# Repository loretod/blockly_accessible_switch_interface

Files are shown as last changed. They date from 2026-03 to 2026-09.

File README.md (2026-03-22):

# Blockly Keyboard Shortcuts Switch Interface
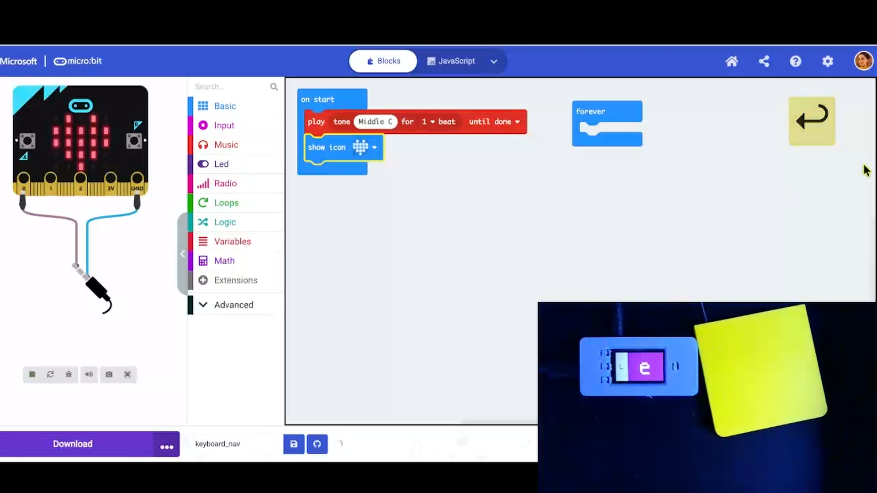
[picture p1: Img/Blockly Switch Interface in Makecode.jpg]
microbit makecode editor with image of a yellow 3d printed switch connected to the switch interface. The interface is showing the letter e on its screen.

## What It Is?
A DIY programmable switch interface that allows users with limited mobility to control computers using one or two adaptive switches. Built with an Adafruit Feather ESP32-S3 Rev TFT board, it features a built-in color display, two 3.5mm switch ports, and USB keyboard emulation of the Blockly keyboard shortcut commands. The device cycles through customizable keyboard commands, making computer access possible for users who cannot operate standard keyboards.

## Who It's For?
**Primary Users:** Individuals with motor impairments (cerebral palsy, muscular dystrophy, spinal cord injuries) who use adaptive switches for computer access and would like to complete in block based coding.

**Builders:** Occupational therapists, AT professionals, special education teachers, makers, family members, and caregivers creating affordable assistive technology solutions.

**Skill Level:** Intermediate - requires basic soldering, CircuitPython programming, and 3D printing.

## Key Features
✓ Two 3.5mm jack ports for standard AT switches  
✓ Built-in 240×135 color TFT display  
✓ USB HID keyboard (works with all computers, no drivers needed)  
✓ Fully customizable keycode list    
✓ 3D printable enclosure
✓ Open-source hardware and software  

## Bill of Materials
- Adafruit Feather ESP32-S3 Rev TFT (~$25)
- 2× 3.5mm mono jacks (~$2)
- Wire, screws, 3D printed enclosure
- **Total Cost: ~$30** (vs. $200-500 for commercial alternatives)

## Critical Safety Warnings

⚠️ **NOT A MEDICAL DEVICE** - This is an educational DIY project, not certified by FDA or any regulatory body. Not for life-critical applications.

⚡ **ELECTRICAL HAZARDS** - Ensure proper insulation and connections. Test thoroughly before use.

💻 **DEVICE BEHAVIOR** - Sends keystrokes to whatever application has focus. Test in safe environments first.

## Professional Guidance
- **Consult with occupational therapists or AT specialists** for assistance
- Professional assessment recommended for switch placement and configuration
- This device should complement, not replace, professional AT services

## License & Attribution

**Creative Commons Attribution-ShareAlike 4.0 International (CC BY-SA 4.0)**

You are free to:
- **Share** — copy and redistribute the material in any medium or format
- **Adapt** — remix, transform, and build upon the material for any purpose, even commercially

Under the following terms:
- **Attribution** — You must give appropriate credit to the original creator, provide a link to the license, and indicate if changes were made. You may do so in any reasonable manner, but not in any way that suggests the licensor endorses you or your use.
- **ShareAlike** — If you remix, transform, or build upon the material, you must distribute your contributions under the same CC BY-SA 4.0 license as the original.
- **No additional restrictions** — You may not apply legal terms or technological measures that legally restrict others from doing anything the license permits.

**Attribution Format:**
"Adaptive Switch Interface Device" by Zero Day Camp, licensed under CC BY-SA 4.0. Available at [[Blockly Accessible Interface](https://github.com/loretod/blockly_accessible_switch_interface/tree/main)].

When sharing modifications or derivatives:
- Maintain all safety warnings and disclaimers
- Clearly indicate what changes were made
- Share improvements back with the community
- Use the same CC BY-SA 4.0 license

This open-source approach ensures the assistive technology community can freely build, improve, and share solutions while protecting creators and maintaining safety standards.

## No Warranty Disclaimer
This project is provided **"as-is"** without warranties of any kind. The creator is not liable for any damages, injuries, or losses from use or misuse. You assume all responsibility for safe construction, testing, and operation. **Build and use at your own risk.**

## Getting Started
[Build instructions and video are available here](https://docs.google.com/presentation/d/e/2PACX-1vRLB-ssaZ2lQKfzIOw7MU3ilnS_D7XAcPhWdcv4CS0tsQ7e1NFE6QulaQyW4kVeWO49AM5KeUvafYBN/pub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)

---

## Next Iteration 
Roadmap for this project includes:
- Creating a wireless bluetooth version
- Creating a solderless version using the micro:bit controller
---

**Feedback?**
Please report any [issues and bugs](https://github.com/loretod/blockly_accessible_switch_interface/issues).

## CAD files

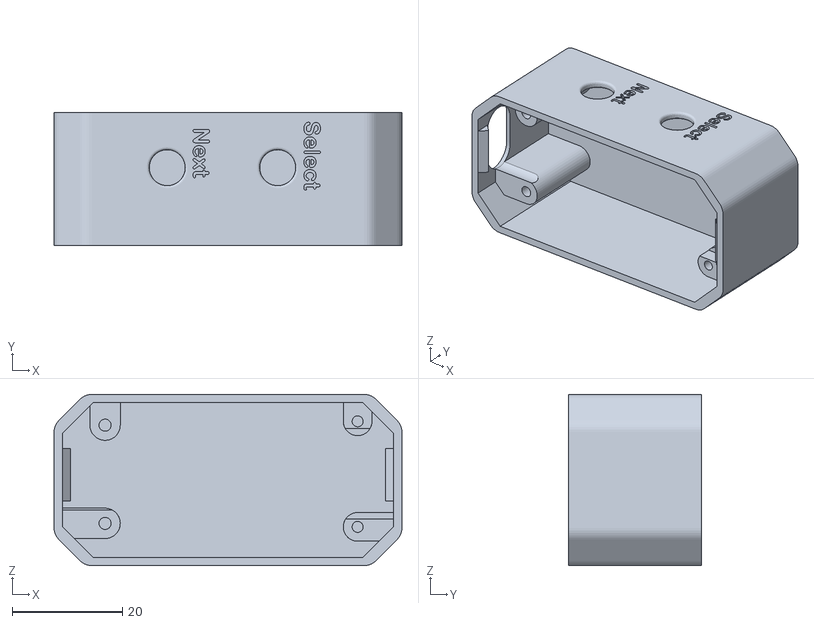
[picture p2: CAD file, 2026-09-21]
STL/TFT Switch Interface Case/Blockly Interface Bottom.stl
63.0 x 24.1 x 31.0

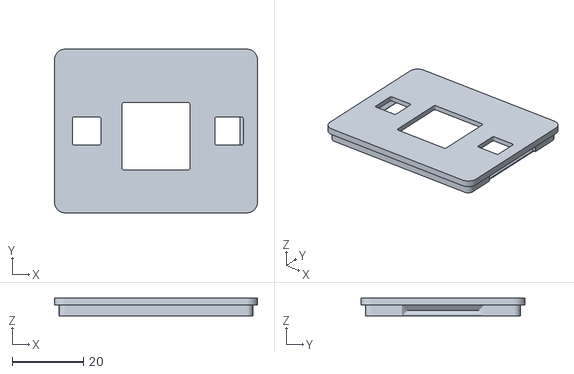
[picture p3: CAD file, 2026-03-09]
Working Files/Microbit Switch Case/Microbit Switch Case Top.stl
57.0 x 46.0 x 5.00

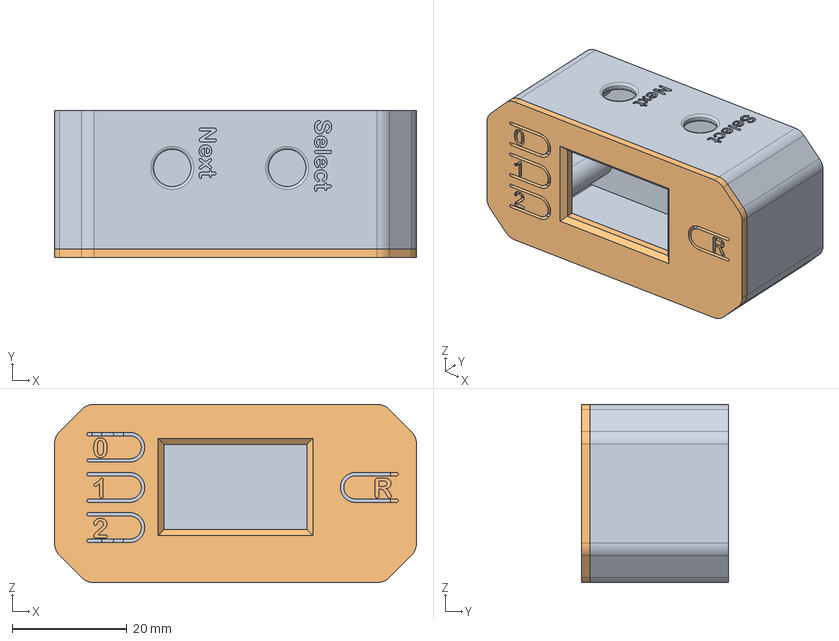
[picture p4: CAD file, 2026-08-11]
STL/TFT Switch Interface Case/Blockly Switch Interface.step
63.0 x 25.6 x 31.0 mm

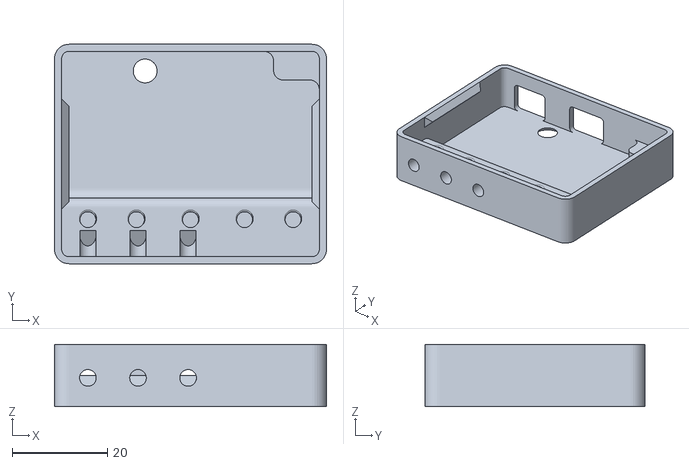
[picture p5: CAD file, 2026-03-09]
Working Files/Microbit Switch Case/Microbit Switch Case Bottom.stl
57.0 x 46.0 x 13.0

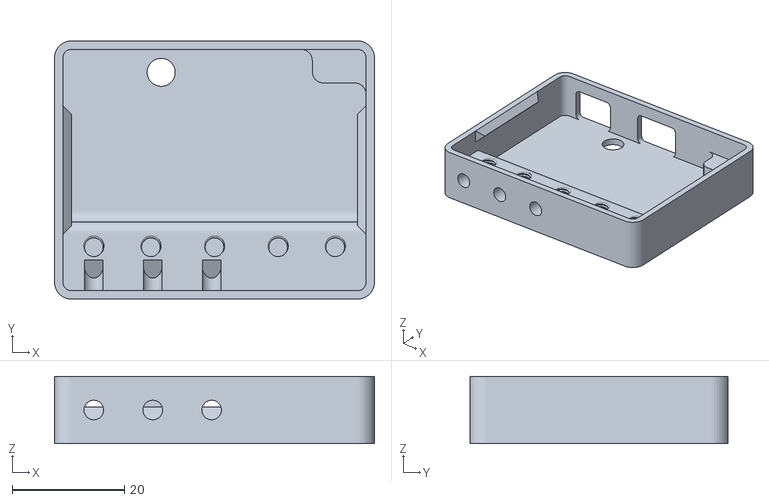
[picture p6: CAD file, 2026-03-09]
Working Files/Microbit Switch Case/Microbit Switch Bottom.stl
57.0 x 46.0 x 12.0

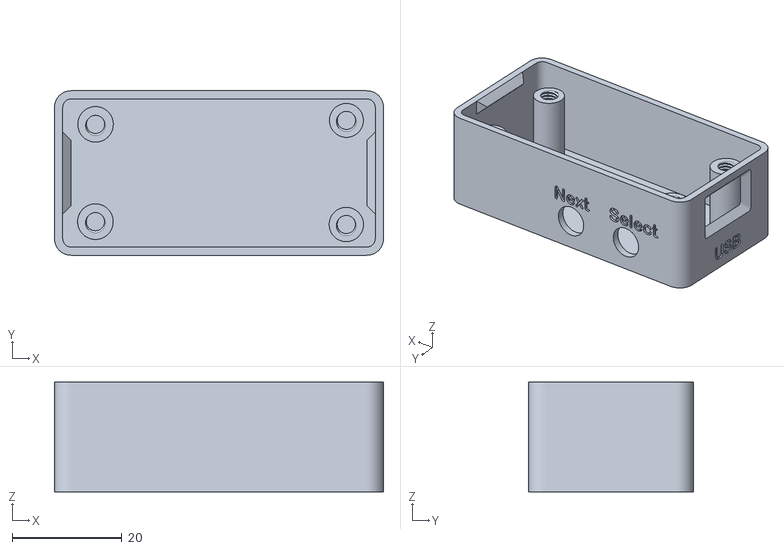
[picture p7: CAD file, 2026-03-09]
STL/TFT Switch Interface Case/TFT Case Bottom V3.stl
60.0 x 30.0 x 20.0

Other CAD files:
STL/TFT Switch Interface Case/TFT Case Bottom V2.stl
STL/TFT Switch Interface Case/Blockly Switch Interface.f3z

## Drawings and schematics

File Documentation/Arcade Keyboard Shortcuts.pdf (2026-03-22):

# Keyboard Shortcuts

### Makecode Arcade

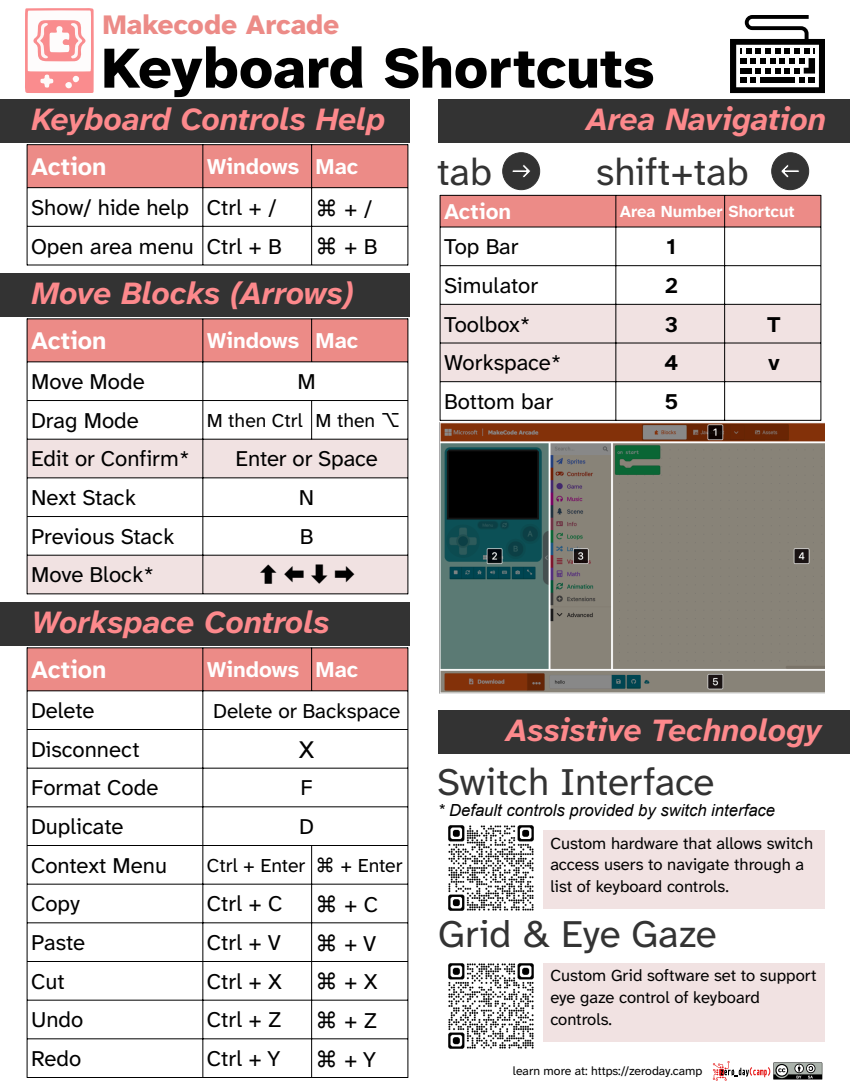
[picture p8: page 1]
Workspace Controls; Area Navigation; Assistive Technology; Open area menu; Ctrl + B; Top Bar; tab; Switch Interface; shift+tab

Keyboard Controls Help

Action | Windows | Mac
Show/ hide help | Ctrl + / | ⌘ + /

Action | Area Number | Shortcut

Move Blocks (Arrows)

Simulator | 2
Toolbox* | 3 | T
Workspace* | 4 | v
Bottom bar | 5

Move Mode | M
Drag Mode | M then Ctrl | M then ⌥
Edit or Confirm* | Enter or Space
Next Stack | N
Previous Stack | B
Move Block* | ⬆ ⬅ ⬇ ➡

Delete | Delete or Backspace
Disconnect | X
Format Code | F
Duplicate | D
Context Menu | Ctrl + Enter | ⌘ + Enter
Copy | Ctrl + C | ⌘ + C
Paste | Ctrl + V | ⌘ + V
Cut | Ctrl + X | ⌘ + X
Undo | Ctrl + Z | ⌘ + Z
Redo | Ctrl + Y | ⌘ + Y

* Default controls provided by switch interface

Custom hardware that allows switch
access users to navigate through a
list of keyboard controls.
Grid & Eye Gaze

Custom Grid software set to support
eye gaze control of keyboard
controls.

learn more at: https://zeroday.camp

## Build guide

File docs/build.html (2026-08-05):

Skip to main content

Step-by-step guide

# Build Instructions

Everything you need to assemble, wire, and install firmware — from parts list to first boot.

Watch the video walkthrough ↓ View Google Slide Instructions (https://docs.google.com/presentation/d/e/2PACX-1vRLB-ssaZ2lQKfzIOw7MU3ilnS_D7XAcPhWdcv4CS0tsQ7e1NFE6QulaQyW4kVeWO49AM5KeUvafYBN/pub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)

Step 01

## Build Instructions

Step 02

## Configuration (optional)

Without a config.py the device uses built-in defaults. To customise:

1. Open the Shortcut Configurator in your browser.
2. Select your OS and adjust shortcuts and timing as needed.
3. Click Generate config.py then Download config.py.
4. Copy the file to the root of CIRCUITPY — the device reloads automatically.

✓ Video walkthrough available (https://www.youtube.com/watch?v=kUqRWDpYum8)

Step 03

## First Boot

Power via USB. The TFT shows the mode-select screen with three zones:

- Left — D0 — Direct Switch Mode (Mode 0)
- Centre — D1 / A2 — Single-switch scanning mode
- Right — D2 / A1 — Two-switch direct mode

Press the relevant onboard button or external switch to enter a mode. To return to the mode-select screen, press the board's RESET button. In Mode 0 you can also hold an external switch for 1.5 s to exit (useful when the onboard buttons aren't reachable).

ℹ Can't reach the onboard D0 button? Double-click either external switch (A1 or A2) at the mode-select screen to jump straight into Mode 0 — Direct Switch.

Step 04

## Switch Modes Reference

### Single-Switch (A2)

One switch controls everything — short press to select, hold to auto-scan.

Short pressSelect & send current item

Hold (2s)Start auto-scanning

Press during scanSelect, stop scanning

D0Return to mode select

### Two-Switch (A1 + A2)

Separate navigate and select switches for faster, direct control.

A1 pressAdvance to next item

A2 pressSelect & send current item

D0Return to mode select

ℹ Single-switch and two-switch modes can also be selected at startup with the external switches: A2 (select) for single-switch mode, A1 (nav) for two-switch mode. To leave any mode, press the board's RESET button (Mode 0 can also be exited by holding a switch).

Mode 0

## Direct Switch Mode

Mode 0 maps each external switch directly to a single, immediate action — no scanning or navigation required. It is designed for users who need a simple, low-effort input method or who want to control mouse and media functions with their switches.

### Direct Switch (Mode 0)

Each switch fires one action immediately on press. Default: Switch 1 = Enter, Switch 2 = Tab. Fully configurable in the Shortcut Configurator.

A1 tapSwitch 1 action (default: Enter)

A2 tapSwitch 2 action (default: Tab)

A1/A2 hold (1.5 s)Return to mode select

RESET buttonReturn to mode select

### How to enter Mode 0

Method | How | Best for
D0 | Press onboard D0 button at mode-select screen | Initial setup, tester access
Double-click | Double-click either external switch (A1 or A2) at the mode-select screen within 0.4 s | Users who cannot reach onboard buttons
config.py | Run run_direct_switch_mode() as the first call in the main loop | Dedicated single-purpose device

ℹ Because a single external-switch click waits briefly (the double-click window, default 0.4 s) to watch for a second click, entering single- or two-switch mode via an external switch has a short deliberate delay. The onboard D1 / D2 buttons enter those modes instantly.

### How to exit Mode 0

Method | How | Best for
Hold a switch | Hold A1 or A2 for 1.5 s — a short tap still fires the action, only a long hold exits | Users who entered by double-click
RESET | Press the board's onboard RESET button | When the board is reachable

### Supported action types

Type | What it does | Example
Keyboard key | Press (and release) any key or key combo | Enter, Tab, Ctrl+C, Cmd+Space
Mouse click | Left, right, or middle button click | Left click for activation
Mouse scroll | Scroll up or down by N ticks per press | Scroll down a page
Mouse move | Move pointer by X/Y pixels per press | Nudge cursor right
Media control | Play/pause, volume, track skip, mute, brightness | Play/pause music

ℹ Customise both switch actions in the Shortcut Configurator under Mode 0 — Direct Switch Actions, then download and drop the generated config.py onto your device.

Step 05

## Display (optional)

The Feather ESP32-S3 TFT has a small built-in display that shows the active shortcut, next shortcut and connection status. Users with low vision may benefit from the Display Tool as an alternative to the small onboard screen. The web app tool provides a larger, high contrast, more readable interface for displaying information and text to speech support if enabled.

Watch the walkthrough below for a live demo of the display in action.

✓ Note: This tool is only support by Chrome or Edge browsers that support WebUSB. TTS is only supported on computers. This tool has not yet been tested on mobile devices.

BASI.

Open source — Creative Commons CC BY-SA 4.0

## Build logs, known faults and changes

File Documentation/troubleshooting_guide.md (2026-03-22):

# Switch Interface Troubleshooting Guide

## Quick Diagnostic Checklist
Before diving into specific issues, verify these basics:
- [ ] CircuitPython 9.0+ or 10.x is installed
- [ ] TinyUF2 Bootloader was updated
- [ ] All required libraries are in the `lib` folder
- [ ] USB cable is a data cable (not charge-only)
- [ ] Switches are normally-open momentary type
- [ ] Board backlight is on (screen should glow)
- [ ] Serial console shows no error messages

---

## Display Issues

### Problem: Display is completely blank/black
**Symptoms:** Screen is dark, no text visible, but device appears powered

**Solutions:**
1. **Check backlight pin**
   - Open serial console and look for "Backlight enabled" message
   - If missing, backlight pin detection failed
   - Manually set backlight: `backlight = digitalio.DigitalInOut(board.D45)`

2. **Verify display initialization**
   - Serial console should show "Display initialized: 240x135"
   - If you see "AttributeError: 'NoneType'", display failed to initialize
   - Check that `adafruit_st7789.mpy` is in the `lib` folder

3. **Test with simple code**
   ```python
   import board
   import displayio
   import terminalio
   from adafruit_display_text import label
   
   displayio.release_displays()
   spi = board.SPI()
   display_bus = displayio.FourWire(spi, command=board.D6, 
                                     chip_select=board.D5, reset=board.D9)
   import adafruit_st7789
   display = adafruit_st7789.ST7789(display_bus, width=240, height=135,
                                     rotation=270, rowstart=40, colstart=53)
   
   splash = displayio.Group()
   text = label.Label(terminalio.FONT, text="TEST", color=0xFFFFFF, x=50, y=50, scale=3)
   splash.append(text)
   display.root_group = splash
   ```

4. **Library version mismatch**
   - CircuitPython 10.x requires 10.x libraries
   - Download matching library bundle from circuitpython.org/libraries
   - Delete old libraries and install fresh ones

### Problem: Display shows garbage/corrupted text
**Symptoms:** Screen shows random pixels, wrong colors, or garbled text

**Solutions:**
1. **Check SPI configuration**
   - Baudrate too high: Lower from 24MHz to 12MHz
   - Change: `spi.configure(baudrate=12000000)`

2. **Verify rotation and offsets**
   - Wrong rotation causes display issues
   - Ensure: `rotation=270, rowstart=40, colstart=53`
   - Try rotation values: 0, 90, 180, 270

3. **Power supply issue**
   - USB port may not provide enough power
   - Try different USB port or powered hub

### Problem: Display works but text is too dim
**Symptoms:** Can barely see text, very faint display

**Solutions:**
1. **Backlight not fully on**
   - Verify backlight pin: `backlight.value = True`
   - Try toggling: `backlight.value = False` then `backlight.value = True`

2. **Check power**
   - Low USB power can dim display
   - Test with different USB cable

---

## Switch Input Issues

### Problem: Switches don't respond at all
**Symptoms:** Pressing switches does nothing, no navigation or selection

**Solutions:**
1. **Test switch continuity**
   - Use multimeter to verify switch closes circuit when pressed
   - Check 3.5mm jack wiring: Tip and Sleeve should connect when pressed
   - Verify jack is fully inserted

2. **Check pin connections**
   - Navigate switch: Jack tip → A0, sleeve → GND
   - Select switch: Jack tip → A1, sleeve → GND
   - Verify solder joints are solid

3. **Test pins in serial console**
   - Add debug code:
   ```python
   print(f"A0 value: {switch_nav.value}")
   print(f"A1 value: {switch_select.value}")
   ```
   - Should show `True` when not pressed, `False` when pressed

4. **Wrong switch type**
   - Device requires **normally-open** switches
   - Normally-closed switches will behave reversed
   - Latching switches won't work (must be momentary)

### Problem: Switches trigger erratically or double-trigger
**Symptoms:** Single press causes multiple actions, unpredictable behavior

**Solutions:**
1. **Increase debounce time**
   - Default is 0.2 seconds
   - Increase: `debounce_time = 0.3` or `0.4`
   - Helps with bouncy mechanical switches

2. **Check for loose connections**
   - Wiggle jack while testing
   - Resolder connections if intermittent
   - Verify jack is firmly mounted

3. **Electrical noise**
   - Add small capacitor (0.1µF) across switch terminals
   - Keep switch wires short and away from power wires
   - Use shielded cable if available

### Problem: Only one switch works
**Symptoms:** One switch navigates/selects correctly, other does nothing

**Solutions:**
1. **Verify both pins configured**
   - Check both `switch_nav` and `switch_select` are defined
   - Ensure both have `pull = digitalio.Pull.UP`

2. **Test individual pins**
   - Swap switch connections to isolate problem
   - If problem follows the switch → bad switch/cable
   - If problem stays with pin → check code/wiring

3. **Pin conflict**
   - Ensure A1 and A2 aren't used elsewhere
   - Check for pin conflicts with display or other features

---

## USB HID / Keyboard Issues

### Problem: Keystrokes not received by computer
**Symptoms:** Display shows "SENT!" but computer doesn't respond

**Solutions:**
1. **Check USB HID initialization**
   - Serial console should show "USB HID Keyboard initialized"
   - If missing, HID failed to initialize
   - Try unplugging and replugging USB

2. **Verify computer recognizes device**
   - **Windows:** Device Manager → Human Interface Devices → "Adafruit Feather ESP32-S3"
   - **Mac:** System Information → USB → Look for keyboard device
   - **Linux:** `lsusb` should show Adafruit device

3. **Test with text editor**
   - Open Notepad/TextEdit
   - Click inside to give it focus
   - If works in editor but not other apps → app-specific issue

4. **Security software blocking**
   - Antivirus may block USB HID devices
   - Temporarily disable to test
   - Add exception for CircuitPython device

### Problem: Wrong keys being sent
**Symptoms:** Press switch, but wrong character appears

**Solutions:**
1. **Verify keycode mapping**
   - Check KEYCODES array matches display
   - Ensure index is correct
   - Common mistake: Display shows one key but sends another

2. **Keyboard layout mismatch**
   - Some keys depend on OS keyboard layout
   - Test with basic keys first (letters, numbers, arrows)
   - Avoid symbols if layout uncertain

3. **Stuck modifier keys**
   - If SHIFT/CTRL/ALT stuck, all keys will be wrong
   - Add to code: `keyboard.release_all()` before every send

---

## CircuitPython Issues

### Problem: Code doesn't auto-reload
**Symptoms:** Changes to code.py don't take effect

**Solutions:**
1. **Manual reload**
   - Press CTRL+D in serial console
   - Or press physical RESET button
   - Or save code.py again

2. **Auto-reload disabled**
   - Check for `supervisor.disable_autoreload()`
   - Remove or comment out

3. **USB connection issue**
   - Unplug and replug USB
   - Try different USB cable/port
   - Check CIRCUITPY drive is mounted

### Problem: "ImportError" for libraries
**Symptoms:** Error says module not found

**Solutions:**
1. **Library not installed**
   - Download CircuitPython library bundle
   - Match version to your CircuitPython version
   - Copy required libraries to `lib` folder

2. **Wrong library version**
   - CircuitPython 10.x needs 10.x libraries
   - Check bundle version number
   - Delete old libraries and reinstall

3. **Library name mismatch**
   - Ensure exact spelling: `adafruit_display_text` (folder)
   - Not `.mpy` files for folders
   - Check capitalization

### Problem: "MemoryError" when running code
**Symptoms:** Code runs then crashes with memory error

**Solutions:**
1. **Too many libraries**
   - Remove unused imports
   - Use `.mpy` compiled libraries instead of `.py`
   - Delete unused libraries from `lib`

2. **Display groups too large**
   - Reduce number of label objects
   - Simplify graphics
   - Reuse groups instead of creating new ones

3. **Firmware issue**
   - Update to latest CircuitPython
   - Try stable vs. beta versions

---

## Common Error Messages

| Error | Meaning | Solution |
|---|---|---|
| `AttributeError: 'module' object has no attribute 'TFT_CS'` | Pin names changed in CP version | Use pin detection code or manual pin assignment |
| `AttributeError: 'NoneType' object has no attribute 'width'` | Display failed to initialize | Check display libraries and initialization code |
| `ImportError: no module named 'adafruit_st7789'` | Missing display driver | Install `adafruit_st7789.mpy` in lib folder |
| `OSError: [Errno 19] No such device` | USB HID not available | Check `usb_hid` is enabled in boot.py |
| `ValueError: Not a valid keycode` | Wrong keycode constant | Use `Keycode.NAME` format, check spelling |
| `MemoryError` | Out of RAM | Remove unused code/libraries, use .mpy files |

---

## Still Having Issues?

### Diagnostic Code
Run this to check your setup:
```python
import board
import supervisor
print(f"CircuitPython version: {supervisor.runtime.version}")
print(f"Board: {board.board_id}")
print("Available pins:", dir(board))
```

### Where to Get Help
1. [**Adafruit Forums**](forums.adafruit.com)
2. [**CircuitPython Discord**](adafru.it/discord)
3. **GitHub Issues:** [Project repository Issues](https://github.com/loretod/blockly_accessible_switch_interface/issues)

### Before Asking for Help
Include this information:
- CircuitPython version
- Board type (Feather ESP32-S3 Rev TFT)
- Libraries installed (and versions)
- Complete error message from serial console
- What you've already tried
- Photo of wiring if relevant

---

## Safety Reminder
If experiencing any of these issues, **stop use immediately**:
- 🔥 Burning smell or smoke
- ⚡ Sparks or short circuits
- 💧 Water damage or moisture inside

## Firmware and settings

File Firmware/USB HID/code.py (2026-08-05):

"""
Switch Interface for Adafruit Feather ESP32-S3 Rev TFT
USB HID Version — Triple Mode with Onboard Mode Selection
Uses built-in 1.14" 240x135 color TFT display
Compatible with CircuitPython

EXTERNAL SWITCHES (3.5mm jacks, wired to GND, Pull.UP active LOW):
  A1 → Navigate switch
  A2 → Select / Single switch

ONBOARD BUTTONS / EXTERNAL SWITCHES (mode selection):
  D0 (onboard)             → Direct Switch Mode (Mode 0)
  D1 (onboard) or A2       → Enter Single-Switch Scanning Mode
  D2 (onboard) or A1       → Enter Two-Switch Mode

  EXTERNAL SWITCHES at the mode-select screen:
    Single-click A2 (select) → Single-Switch Scanning Mode
    Single-click A1 (nav)    → Two-Switch Mode
    Double-click A1 or A2    → Direct Switch Mode (Mode 0)
  (Note: a single external-switch click waits one DOUBLE_CLICK_WINDOW before
   committing, so a second click can be detected for Mode 0.)

─── DIRECT SWITCH MODE (Mode 0) ───────────────────────
  A1 TAP    : Send Switch 1 action (default: Enter)
  A2 TAP    : Send Switch 2 action (default: Tab)
  A1/A2 HOLD (≥ SWITCH_HOLD_EXIT_SECS) : Back to Mode Select
  D0        : Back to Mode Select
  (Customisable via config.py — supports keyboard, mouse & media)

─── SINGLE-SWITCH MODE ─────────────────────────────────────
  A2 SHORT PRESS  (≤ MAX_SHORT_PRESS_SECS)  : Select & send current item
  A2 HOLD         (≥ HOLD_TO_SCAN_SECS)     : Start auto-scanning
  A2 PRESS during scan                      : Select & send, stop scanning
  D0                                        : Back to Mode Select

─── TWO-SWITCH MODE ────────────────────────────────────────
  A1  : Advance to next item
  A2  : Select & send current item
  D0  : Back to Mode Select

(D0 is dual-purpose: at the mode-select screen it jumps straight into
 Mode 0; from inside ANY active mode it returns to the mode-select screen.)

─── SUBMENUS (Modes 1 & 2 only) ─────────────────────────────
  Any KEYCODES entry can be a SUBMENU ENTRY POINT (it has a
  "submenu" list). Selecting it sends its own keycode first
  (e.g. to open an on-screen menu on the host) — unless "kc"
  is empty, which marks a pure organisational folder with no
  keystroke of its own — then the scan/nav list switches to
  just that entry's child items. If the entry's "auto_exit"
  is True, picking a child item automatically returns to the
  parent list afterwards. If False, a synthetic "◂ back" item
  is added to the child list so several child items can be
  picked in a row before manually returning.
"""

import time
import board
import digitalio
import displayio
import terminalio
try:
    from fourwire import FourWire
except ImportError:
    from displayio import FourWire
import adafruit_st7789
from adafruit_display_text import label
import usb_hid
from adafruit_hid.keyboard import Keyboard
from adafruit_hid.keycode import Keycode

# Optional mouse / consumer control — only used by Mode 0 (Direct Switch).
# Imported here (not lazily) so config.py can reference Mouse /
# ConsumerControlCode directly when defining SWITCH1_ACTION / SWITCH2_ACTION.
try:
    from adafruit_hid.mouse import Mouse
    _mouse_available = True
except ImportError:
    _mouse_available = False

try:
    from adafruit_hid.consumer_control import ConsumerControl
    from adafruit_hid.consumer_control_code import ConsumerControlCode
    _consumer_available = True
except ImportError:
    _consumer_available = False

print("Starting Switch Interface...")

# ===============================================
# ===== USER CONFIGURABLE VARIABLES =====
# ===============================================

# --- Single-Switch Mode ---
# How long (seconds) A2 must be held to begin auto-scanning
HOLD_TO_SCAN_SECS = 2.0

# How fast (seconds) the scanner advances to the next item
SCAN_INTERVAL_SECS = 1

# Maximum press duration (seconds) considered a "short press"
MAX_SHORT_PRESS_SECS = 0.5

# --- Two-Switch Mode ---
# Debounce delay (seconds) after a nav or select press
DEBOUNCE_TIME = 0.1

# --- Double-click to enter Mode 0 ---
# Maximum gap (seconds) between two clicks to count as a double-click
DOUBLE_CLICK_WINDOW = 0.4

# --- External switch hold to exit Mode 0 ---
# How long (seconds) an external switch (A1 or A2) must be held in Mode 0
# to return to the mode-select menu.
SWITCH_HOLD_EXIT_SECS = 1.5

# ─── MODE 0: DIRECT SWITCH ACTIONS ─────────────────────────────────────────
#
# Each action is a dict with the key "type" and type-specific fields:
#
#   Keyboard key press:
#     {"type": "key", "keys": [Keycode.ENTER]}
#     {"type": "key", "keys": [Keycode.LEFT_CONTROL, Keycode.C]}
#
#   Mouse button click:
#     {"type": "mouse_click", "button": Mouse.LEFT_BUTTON}   (requires adafruit_hid.mouse)
#
#   Mouse scroll:
#     {"type": "mouse_scroll", "x": 0, "y": 1}   (positive y = scroll up)
#
#   Mouse move:
#     {"type": "mouse_move", "x": 10, "y": 0}
#
#   Media / consumer control:
#     {"type": "media", "code": ConsumerControlCode.PLAY_PAUSE}
#     {"type": "media", "code": ConsumerControlCode.VOLUME_INCREMENT}
#     {"type": "media", "code": ConsumerControlCode.VOLUME_DECREMENT}
#     {"type": "media", "code": ConsumerControlCode.MUTE}
#     {"type": "media", "code": ConsumerControlCode.SCAN_NEXT_TRACK}
#     {"type": "media", "code": ConsumerControlCode.SCAN_PREVIOUS_TRACK}

SWITCH1_ACTION = {"type": "key", "keys": [Keycode.ENTER]}   # A1 press
SWITCH2_ACTION = {"type": "key", "keys": [Keycode.TAB]}     # A2 press

SWITCH1_LABEL  = "Enter"   # Shown on TFT
SWITCH2_LABEL  = "Tab"     # Shown on TFT
SWITCH1_SYMBOL = "ENT"     # Short TFT symbol (1-3 ASCII chars)
SWITCH2_SYMBOL = "TAB"     # Short TFT symbol (1-3 ASCII chars)
# NOTE: the onboard TFT uses terminalio.FONT (a built-in bitmap font) which
# only renders basic ASCII / Latin-1 characters. Emoji and most symbol glyphs
# (e.g. ⏎ ⇥ → ▶) will appear blank. Stick to plain letters/numbers/punctuation.

# ===============================================
# ===== DISPLAY INITIALIZATION =====
# ===============================================

print("\nInitializing display...")
displayio.release_displays()

spi = board.SPI()
tft_cs = board.TFT_CS
tft_dc = board.TFT_DC
tft_reset = board.TFT_RESET
tft_backlight = board.TFT_BACKLIGHT

display_bus = FourWire(
    spi,
    command=tft_dc,
    chip_select=tft_cs,
    reset=tft_reset,
    baudrate=24000000
)

display = adafruit_st7789.ST7789(
    display_bus,
    width=240,
    height=135,
    rowstart=40,
    colstart=52,
    rotation=270,
    bgr=True
)

backlight = digitalio.DigitalInOut(tft_backlight)
backlight.direction = digitalio.Direction.OUTPUT
backlight.value = True

print("Display initialized!")

# ===============================================
# ===== LED SETUP =====
# ===============================================

led = digitalio.DigitalInOut(board.LED)
led.direction = digitalio.Direction.OUTPUT

# ===============================================
# ===== EXTERNAL SWITCH PINS (A1, A2) =====
# Pull.UP — switch wired between pin and GND.
# Pressed = False (LOW).
# ===============================================

switch_nav = digitalio.DigitalInOut(board.A1)
switch_nav.direction = digitalio.Direction.INPUT
switch_nav.pull = digitalio.Pull.UP

switch_select = digitalio.DigitalInOut(board.A2)
switch_select.direction = digitalio.Direction.INPUT
switch_select.pull = digitalio.Pull.UP

def nav_pressed():
    return not switch_nav.value       # Active LOW

def select_pressed():
    return not switch_select.value    # Active LOW

# ===============================================
# ===== ONBOARD BUTTONS (D0, D1, D2) =====
# D0: Pull.UP  → active LOW
# D1: Pull.DOWN → active HIGH
# D2: Pull.DOWN → active HIGH
# ===============================================

button0 = digitalio.DigitalInOut(board.D0)
button0.switch_to_input(pull=digitalio.Pull.UP)

button1 = digitalio.DigitalInOut(board.D1)
button1.switch_to_input(pull=digitalio.Pull.DOWN)

button2 = digitalio.DigitalInOut(board.D2)
button2.switch_to_input(pull=digitalio.Pull.DOWN)

def d0_pressed():
    return not button0.value   # Active LOW

def d1_pressed():
    return button1.value       # Active HIGH

def d2_pressed():
    return button2.value       # Active HIGH

# ===============================================
# ===== USB HID SETUP =====
# ===============================================

time.sleep(1)
keyboard = Keyboard(usb_hid.devices)

_mouse = None
_consumer = None

def get_mouse():
    global _mouse
    if _mouse is None and _mouse_available:
        try:
            _mouse = Mouse(usb_hid.devices)
        except Exception as e:
            print(f"Mouse init failed: {e}")
    return _mouse

def get_consumer():
    global _consumer
    if _consumer is None and _consumer_available:
        try:
            _consumer = ConsumerControl(usb_hid.devices)
        except Exception as e:
            print(f"ConsumerControl init failed: {e}")
    return _consumer

# ===============================================
# ===== KEYCODES AND SYMBOL DEFINITIONS =====
# ===============================================
#
# Each entry in KEYCODES is normally a dict:
#   {
#       "label":  str             human-readable name (shown in serial log)
#       "kc":     [Keycode, ...]   keys sent together when selected
#       "symbol": str              1-4 char glyph shown on the TFT
#
#       "submenu": [ ... ]         OPTIONAL. Present only on a SUBMENU ENTRY
#                                  POINT. A list of child entries (same
#                                  shape as this one, minus "submenu").
#       "auto_exit": bool          OPTIONAL, only meaningful alongside
#                                  "submenu". True = return to the parent
#                                  list right after a child is picked.
#                                  False = stay in the submenu (a "◂ back"
#                                  item is added automatically) so several
#                                  child items can be picked in a row.
#   }
#
# Legacy format is still accepted for old config.py files: a plain
# (label, [Keycode, ...]) tuple, with its symbol looked up from the
# KEY_SYMBOLS dict below. New config.py files generated by the Shortcut
# Configurator always use the dict format above.

KEYCODES = [
    {"label": "tab",         "kc": [Keycode.TAB],         "symbol": ">"},
    {"label": "arrow right", "kc": [Keycode.RIGHT_ARROW], "symbol": "R"},
    {"label": "arrow down",  "kc": [Keycode.DOWN_ARROW],  "symbol": "D"},
    {"label": "enter",       "kc": [Keycode.ENTER],       "symbol": "e"},
    {"label": "arrow left",  "kc": [Keycode.LEFT_ARROW],  "symbol": "L"},
    {"label": "arrow up",    "kc": [Keycode.UP_ARROW],    "symbol": "U"},
    {"label": "delete",      "kc": [Keycode.DELETE],      "symbol": "x"},
    {"label": "escape",      "kc": [Keycode.ESCAPE],      "symbol": "ESC"},
    {"label": "w",           "kc": [Keycode.W],           "symbol": "W"},
    {"label": "t",           "kc": [Keycode.T],           "symbol": "T"},
    {
        "label": "ctrl+b", "kc": [Keycode.LEFT_CONTROL, Keycode.B], "symbol": "B",
        "auto_exit": True,
        "submenu": [
            {"label": "0", "kc": [Keycode.ZERO],  "symbol": "0"},
            {"label": "1", "kc": [Keycode.ONE],   "symbol": "1"},
            {"label": "2", "kc": [Keycode.TWO],   "symbol": "2"},
            {"label": "3", "kc": [Keycode.THREE], "symbol": "3"},
            {"label": "4", "kc": [Keycode.FOUR],  "symbol": "4"},
            {"label": "5", "kc": [Keycode.FIVE],  "symbol": "5"},
        ],
    },
    {
        # The on-screen menu ctrl+enter opens does not respond to direct
        # letter/ctrl-combo shortcuts — it must be navigated with the arrow
        # keys and confirmed with Enter. No auto_exit: arrow down/up as many
        # times as needed, then Enter to confirm, then "back" to return.
        "label": "ctrl+enter", "kc": [Keycode.LEFT_CONTROL, Keycode.ENTER], "symbol": "ENT",
        "auto_exit": False,
        "submenu": [
            {"label": "arrow down", "kc": [Keycode.DOWN_ARROW], "symbol": "D"},
            {"label": "enter",      "kc": [Keycode.ENTER],      "symbol": "e"},
            {"label": "arrow up",   "kc": [Keycode.UP_ARROW],   "symbol": "U"},
        ],
    },
    {
        # A pure organisational folder: "kc" is empty, so selecting the
        # entry point sends no keystroke of its own — it just opens the
        # submenu below. Each child still sends its own real shortcut.
        "label": "Block Actions", "kc": [], "symbol": "BLK",
        "auto_exit": True,
        "submenu": [
            {"label": "cut",       "kc": [Keycode.LEFT_CONTROL, Keycode.X],                    "symbol": "X"},
            {"label": "copy",      "kc": [Keycode.LEFT_CONTROL, Keycode.C],                    "symbol": "C"},
            {"label": "paste",     "kc": [Keycode.LEFT_CONTROL, Keycode.V],                    "symbol": "V"},
            {"label": "duplicate", "kc": [Keycode.D],                                          "symbol": "D"},
            {"label": "delete",    "kc": [Keycode.BACKSPACE],                                  "symbol": "BS"},
            {"label": "undo",      "kc": [Keycode.LEFT_CONTROL, Keycode.Z],                    "symbol": "U"},
            {"label": "redo",      "kc": [Keycode.LEFT_CONTROL, Keycode.LEFT_SHIFT, Keycode.Z], "symbol": "R"},
        ],
    },
]

# Only consulted for legacy tuple-style KEYCODES entries.
KEY_SYMBOLS = {}

# Load user overrides from config.py (if present on CIRCUITPY drive)
try:
    from config import *
except ImportError:
    pass  # config.py missing — use defaults above

# ===============================================
# ===== MENU NORMALIZATION =====
# ===============================================
# Accepts both the new dict format and the legacy tuple format (using
# KEY_SYMBOLS for the latter) and produces a uniform tree of dicts.

def normalize_item(raw, symbols_table):
    if isinstance(raw, dict):
        item = dict(raw)
    else:
        label, kc = raw[0], raw[1]
        item = {"label": label, "kc": kc, "symbol": symbols_table.get(label, "?")}
    item.setdefault("symbol", "?")
    if item.get("submenu"):
        item["submenu"] = [normalize_item(c, symbols_table) for c in item["submenu"]]
        item.setdefault("auto_exit", False)
    return item

def normalize_menu(raw_list, symbols_table):
    return [normalize_item(r, symbols_table) for r in raw_list]

MENU = normalize_menu(KEYCODES, KEY_SYMBOLS)

# ===============================================
# ===== MENU / SUBMENU NAVIGATION STATE =====
# ===============================================

def _back_item():
    """Synthetic item appended to every submenu's child list so the user
    can return to the parent list without sending any keystroke."""
    return {"label": "back", "kc": None, "symbol": "<", "is_back": True}

class MenuFrame:
    """One level of the menu stack: the items currently being scanned or
    navigated, the active index within them, and whether picking a plain
    (non-submenu) item here should automatically pop back to the parent."""
    def __init__(self, items, auto_exit=False):
        self.items = items
        self.index = 0
        self.auto_exit = auto_exit

menu_stack = [MenuFrame(MENU, auto_exit=False)]

def current_frame():
    return menu_stack[-1]

def current_item():
    f = current_frame()
    return f.items[f.index]

def in_submenu():
    return len(menu_stack) > 1

def enter_submenu(item):
    children = list(item["submenu"]) + [_back_item()]
    menu_stack.append(MenuFrame(children, auto_exit=item.get("auto_exit", False)))

def exit_submenu():
    if len(menu_stack) > 1:
        menu_stack.pop()

def advance_index():
    f = current_frame()
    f.index = (f.index + 1) % len(f.items)

def reset_menu():
    """Called whenever a mode is (re)entered — always start at the top."""
    while len(menu_stack) > 1:
        menu_stack.pop()
    menu_stack[0].index = 0

# ===============================================
# ===== DISPLAY HELPERS =====
# ===============================================

SCREEN_WIDTH  = 240
SCREEN_HEIGHT = 135
LEFT_WIDTH    = SCREEN_WIDTH // 4
RIGHT_WIDTH   = SCREEN_WIDTH - LEFT_WIDTH

PURPLE     = 0x800080
SCAN_COLOR = 0x0055FF
DARK_BLUE  = 0x003399
TEAL       = 0x007060   # Mode 0 accent colour
LIGHT_GRAY = 0xAAAAAA
WHITE      = 0xFFFFFF
GREEN      = 0x00CC00
RED        = 0xFF0000
ORANGE     = 0xFF8C00   # submenu entry-point / in-submenu visual cue
SUBMENU_BORDER_PX = 10  # thickness (px) of the submenu-entry outline cue

splash = displayio.Group()
display.root_group = splash

def create_background(color, x, y, width, height):
    bmp = displayio.Bitmap(width, height, 1)
    pal = displayio.Palette(1)
    pal[0] = color
    return displayio.TileGrid(bmp, pixel_shader=pal, x=x, y=y)

def clear_display():
    while splash:
        splash.pop()

def draw_current_screen(flash_color=None, scanning=False):
    """Standard two-pane display, aware of the current submenu context.

    Visual cues (mirroring the color + outline cue used on the configurator
    website for submenu entries):
      - An item that OPENS a submenu gets a thicker ORANGE outline drawn
        behind its normal panel color.
      - While INSIDE a submenu, a small "SUB" badge is shown top-left.
    """
    clear_display()

    f          = current_frame()
    item       = f.items[f.index]
    next_item  = f.items[(f.index + 1) % len(f.items)]

    current_symbol = item.get("symbol", "?")
    next_symbol    = next_item.get("symbol", "?")
    is_entry_point = bool(item.get("submenu"))

    right_color = SCAN_COLOR if scanning else PURPLE

    if is_entry_point:
        # Thicker colored outline behind the normal panel = "opens a submenu"
        border = SUBMENU_BORDER_PX
        splash.append(create_background(ORANGE, LEFT_WIDTH, 0, RIGHT_WIDTH, SCREEN_HEIGHT))
        splash.append(create_background(
            right_color,
            LEFT_WIDTH + border, border,
            RIGHT_WIDTH - 2 * border, SCREEN_HEIGHT - 2 * border
        ))
    else:
        splash.append(create_background(right_color, LEFT_WIDTH, 0, RIGHT_WIDTH, SCREEN_HEIGHT))

    splash.append(label.Label(
        terminalio.FONT, text=current_symbol, color=WHITE, scale=9,
        anchor_point=(0.5, 0.5),
        anchored_position=(LEFT_WIDTH + RIGHT_WIDTH // 2, SCREEN_HEIGHT // 2)
    ))

    splash.append(create_background(LIGHT_GRAY, 0, 0, LEFT_WIDTH, SCREEN_HEIGHT))
    splash.append(label.Label(
        terminalio.FONT, text=next_symbol, color=PURPLE, scale=3,
        anchor_point=(0.5, 0.5),
        anchored_position=(LEFT_WIDTH // 2, SCREEN_HEIGHT // 2)
    ))

    if in_submenu():
        splash.append(label.Label(
            terminalio.FONT, text="SUB", color=ORANGE, scale=1,
            anchor_point=(0.0, 0.0), anchored_position=(2, 2)
        ))

    if flash_color is not None:
        splash.append(create_background(flash_color, 0, 0, SCREEN_WIDTH, SCREEN_HEIGHT))
        splash.append(label.Label(
            terminalio.FONT, text="SENT!", color=WHITE, scale=5,
            anchor_point=(0.5, 0.5),
            anchored_position=(SCREEN_WIDTH // 2, SCREEN_HEIGHT // 2)
        ))

def draw_direct_switch_screen(active=None, flash_color=None):
    """
    Two-pane display for Mode 0.
    active = None | 1 | 2   (which switch was just pressed)
    """
    clear_display()

    half = SCREEN_WIDTH // 2

    # Left pane — Switch 1 (A1)
    left_bg = flash_color if (active == 1 and flash_color) else TEAL
    right_bg = flash_color if (active == 2 and flash_color) else DARK_BLUE

    splash.append(create_background(left_bg,  0,    0, half,                SCREEN_HEIGHT))
    splash.append(create_background(right_bg, half, 0, SCREEN_WIDTH - half, SCREEN_HEIGHT))

    # Vertical divider
    splash.append(create_background(WHITE, half - 1, 0, 2, SCREEN_HEIGHT))

    # Switch 1 label
    splash.append(label.Label(
        terminalio.FONT, text="SW1", color=WHITE, scale=1,
        anchor_point=(0.5, 0.2),
        anchored_position=(half // 2, SCREEN_HEIGHT // 2 - 22)
    ))
    sym1 = SWITCH1_SYMBOL[:3]
    splash.append(label.Label(
        terminalio.FONT, text=sym1, color=WHITE, scale=4,
        anchor_point=(0.5, 0.5),
        anchored_position=(half // 2, SCREEN_HEIGHT // 2 + 4)
    ))

    # Switch 2 label
    splash.append(label.Label(
        terminalio.FONT, text="SW2", color=WHITE, scale=1,
        anchor_point=(0.5, 0.2),
        anchored_position=(half + (SCREEN_WIDTH - half) // 2, SCREEN_HEIGHT // 2 - 22)
    ))
    sym2 = SWITCH2_SYMBOL[:3]
    splash.append(label.Label(
        terminalio.FONT, text=sym2, color=WHITE, scale=4,
        anchor_point=(0.5, 0.5),
        anchored_position=(half + (SCREEN_WIDTH - half) // 2, SCREEN_HEIGHT // 2 + 4)
    ))
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

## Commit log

2026-03-09 Images and firmware versions
    [Box.scad, Microbit Switch Bottom.stl, Microbit Switch Case Bottom.stl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]
2026-03-18 update file structure and read me
    [Box.scad, Microbit Switch Bottom.stl, Microbit Switch Case Bottom.stl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]
2026-08-11 Case Adjustment
    Increased case height by 5mm and moved switch holes up 3mm. Updated keyboard shortcuts quickguide.
    [Blockly Interface Bottom.stl]
2026-08-11 Upload File
    Added feature for uploading existing config.py file for modification. Visual Configurator edits to nest descriptions in details and two columns to separate steps from resources.
    [Blockly Switch Interface.f3z, Blockly Switch Interface.step]
2026-09-21 Update Case bottom
    Update case bottom for better snap fit, USB plug alignment, and contact with top buttons.
    [Blockly Interface Bottom.stl]
2026-10-17 Updated STEP and Fusion files
    Included updated STEP and Fusion versions of confirmed case bottom corrections.
